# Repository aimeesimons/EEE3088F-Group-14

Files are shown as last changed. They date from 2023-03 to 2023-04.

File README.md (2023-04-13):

# EEE3088F-Group-14
Aimee Simons, Ashik John, Kudzi Kadzimu

1. 	Final Project has all the latest kicad files, 
	FullSchematic is the file with all modules combined

2.	PCB Submission contains PCB Files submitted for manufacture

3.	Report Submission contains weekly design assignment reports

4.	Miscellaneous files contains all other files used in the project, 
	THE FILES MAY NOT BE UP TO DATE WITH THE FINAL SUBMISSION!

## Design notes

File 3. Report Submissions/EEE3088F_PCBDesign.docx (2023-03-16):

Q1 Github [1]

https://github.com/aimeesimons/EEE3088F-Group-14.git

Q2 Power Subsystem Failure Management [2]

- Various failure management processes can be implemented that could cater for various failure instances. In the event of component failure, the datasheets of the different components must be carefully read to ensure that the components operate at rated electrical characteristics. The component packages are chosen to be sizes readily available elsewhere, such as the UCT white lab, in the event that components need to be replaced.
- If trace damage occurs, the various test points can be connected with means of an external soldered wire, thus forming an alternate route for current flow. The test points themselves can be used to check for continuity in the traces, and identify exact traces with damage.
- Where possible, components were selected to be basic parts, which the supplier is more likely to have ready access to. In the cases where extended parts need to be used, the different parts available can be sorted by stock available, thus mitigating the chances component shortage. In the event that component shortage still occurs, most components can be chosen to be common package sizes, so that they can be sourced and soldered on locally.
- Designs will be simulated beforehand, to lower chances of error. Test points will be added for debugging purposes and 0Ω resistors will be used to break connection and bypass the different components if required.

Q3 Sensing Subsystem Failure Management [2]

- Components could become damaged due to various circumstances, whether it be current overload or damage in transit. With regards to damage due to current overload, zero-ohm resistors can be placed within the circuit and used as fuses to prevent damages that could be caused to these components. Components damaged in transit could be remedied by removing that damaged component and soldering on an alternative component. If it is the worst-case scenario and most of the components fail, a breadboard can be used to show the functionality of the HAT, in the meantime, before making adjustments to the circuit schematic and/or ordering a new PCB.
- In terms of trace damage; this could be damage to the point of causing an open circuit; short wires could be soldered to connect components previously disconnected by damaged traces. Test points will be located at several points in the circuit to test continuity, which should indicate whether there has been any trace damage.
- In terms of availability of parts, on the JLCPCB website, The TTP223 chip seems to be out of stock and/or discontinued. A similar chip which works in the same way and is available was found as an alternative. In terms of specialised components, such as the use of a variable capacitor, which has very limited stock, this will prove to be trickier. An alternative would have to be to purchase a normal capacitor.
- There could also be errors in the design that went undetected and was only discovered upon manufacture. If the error has to do with the connections, traces could be purposefully damaged or open circuits can be made in order to physically make the correct connections using wires. As mentioned above, ordering a normal capacitor instead of a variable capacitor could prove to have some consequences. Ordering a specific capacitor would require calculations before purchase, in order to adjust the sensitivity of the touch sensor. This could, however, result in either a very sensitive touch sensor (too sensitive - meaning you can just hover your finger over the touch-pad and it will be detected) or not sensitive enough (meaning it will be very difficult for the chip to detect any touch at all). This capacitor connection should therefore not be too close to other components, as it would have to be easily removable and replaceable.

Q4 Microcontroller interfacing Failure Management [2]

To manage failures in our circuit design we can take.

(i) Component failure/destruction:

We will use high-quality but affordable components from a reputable manufacturer.

(ii) Trace damage:

Make sure the traces are not too thin and can handle the expected current.

Add protective components like TVS diodes to prevent damage to the traces.

Place vias to allow for the routing of the trace on the other side of the board.

(iii) Component shortage:

Choose components that are readily available.

Select alternative components with similar specifications that have huge stock and use them in the design.

Work with the PCB assembly house to find replacement components if the original component is no longer in stock.

(iv) Errors in circuit design:

Use simulation software to verify the circuit design before manufacturing.

Add test points for each circuit block to allow for easy debugging and testing.

Use a modular design approach to reduce the impact of design errors on the entire circuit.

By incorporating these measures, you can manage failures in your circuit design, ensuring a reliable and functional PCB.

Q5 Power Subsystem Schematic [2]

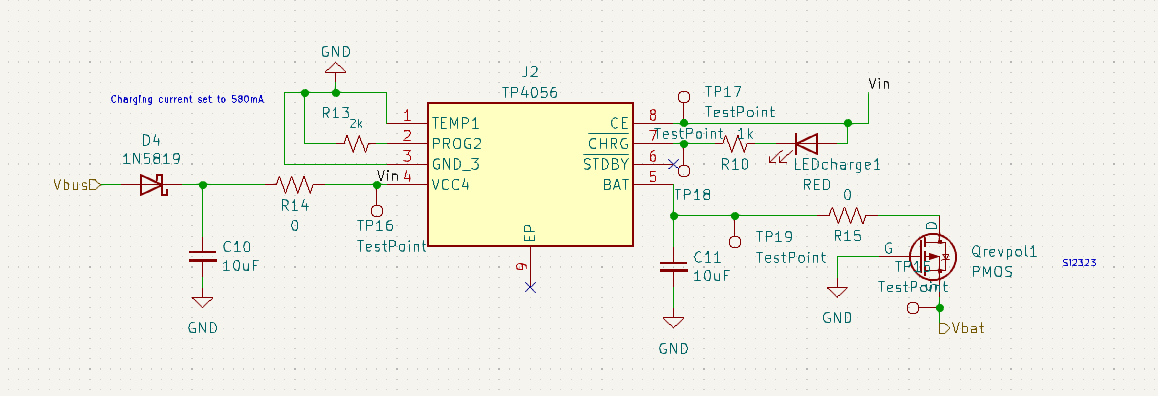
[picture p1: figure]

Charging Module

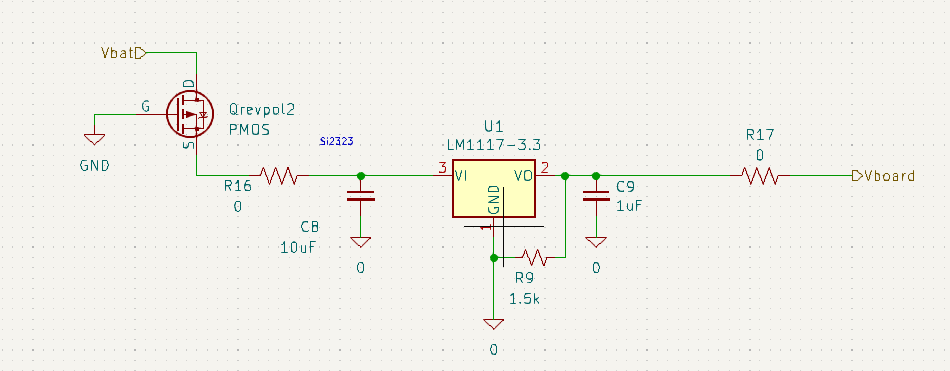
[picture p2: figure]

Regulating Module

Q6 Sensing Subsystem Schematics [2]

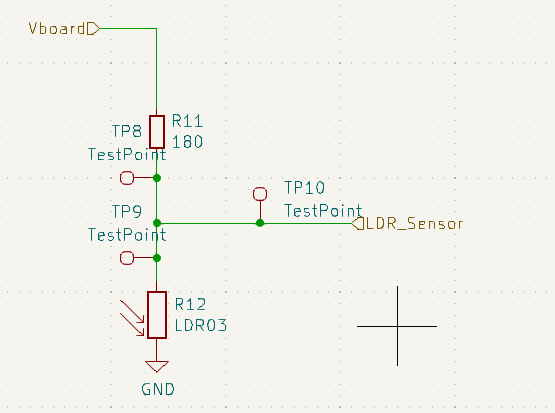
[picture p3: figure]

Analogue Sensor

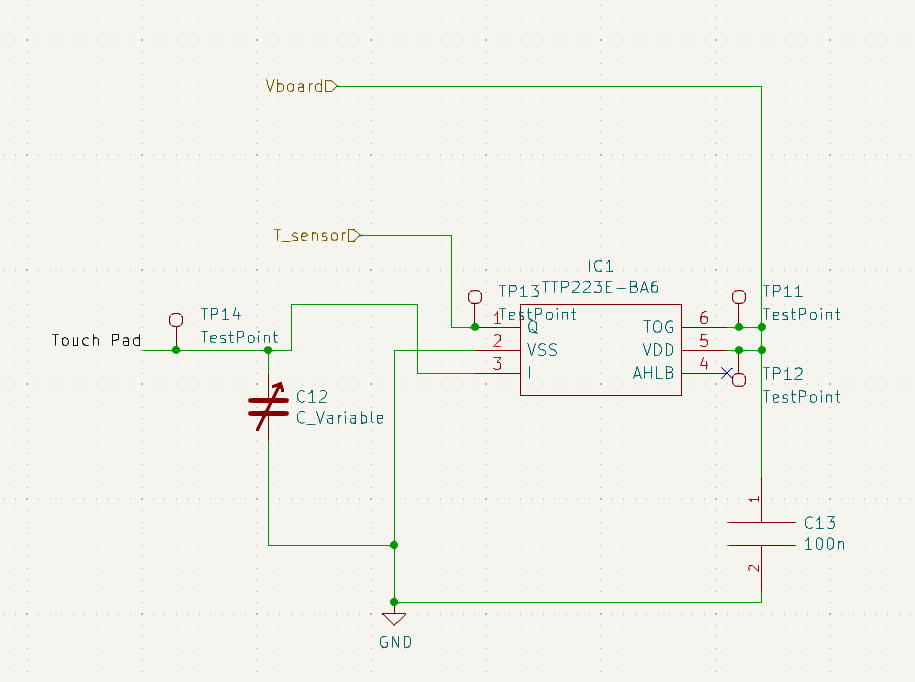
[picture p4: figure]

Digital Sensor

Q7 Microcontroller Interfacing Schematic [2]

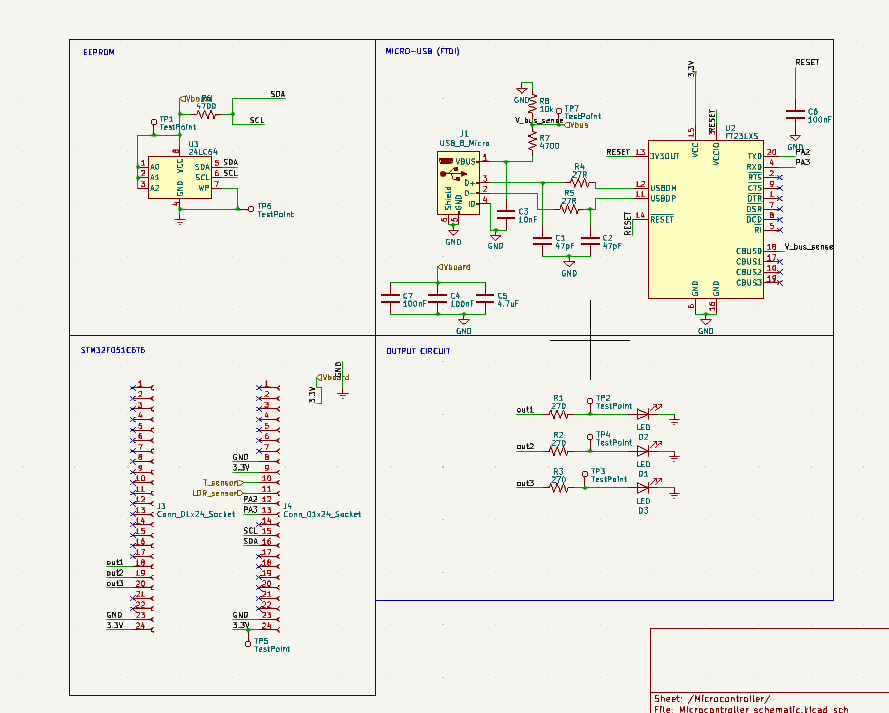
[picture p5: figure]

Microcontroller module

Q8 Updated ERCs [2]

- All hierarchal labels should be connected and should be connected properly.
- All net labels should be identical, example T_Sensor and T-sensor will cause confusion.
- All pins that are to be unconnected should have an indicator that they are unused.
- All components should be named uniquely, with no duplicates.
- Check that current is limited for important chips/components.

Q9 DRCs [2]

Q10 Updated BOM [5]

https://github.com/aimeesimons/EEE3088F-Group-14/blob/main/FullSchematic/FullSchematic/FullSchematic_Spreadsheet.xlsx

Q11 PCB [15]

EEE3088F PCB Design

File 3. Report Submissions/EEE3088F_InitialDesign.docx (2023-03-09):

Q1 Github [1]

https://github.com/aimeesimons/EEE3088F-Group-14.git

Q2 Power Subsystem Failure Management [5]

In text, briefly describe what measures you’ve taken in your circuit design that will enable you to manage failures such as but not necessarily limited to: (i) component failure/destruction, (ii) trace damage, (iii) component shortage (if at PCB assembly time your component is no longer in stock), (iv) errors in your circuit design that are only detected post manufacture.

Q3 Sensing Subsystem Failure Management [5]

(i) component failure/destruction

(ii) trace damage

(iii) component shortage (if at PCB assembly time your component is no longer in stock)

(iv) errors in your circuit design that are only detected post manufacture.

Q4 Microcontroller interfacing Failure Management [5]

In text, briefly describe what measures you’ve taken in your circuit design that will enable you to manage failures such as but not necessarily limited to: (i) component failure/destruction, (ii) trace damage, (iii) component shortage (if at PCB assembly time your component is no longer in stock), (iv) errors in your circuit design that are only detected post manufacture.

Q5 Power Subsystem Schematic [10]

Q6 Sensing Subsystem Schematics [10]

Q7 Microcontroller Interfacing Schematic [10]

Q8 Planned ERCs [5]

Q9 Updated BOM [4]

EEE3088F Initial Design

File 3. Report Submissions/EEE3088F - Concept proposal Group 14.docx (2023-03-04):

Q1 Enviro sensing HAT Concept [5]

Our team has come up with the idea to design and build a portable torch with auto-adjusting brightness. This project is engineered specifically for the age of load-shedding we are currently in, and caters to all audiences with a niche target on students. The device is easily rechargeable, using a 5V input, it could be connected to a laptop or a car. The board also uses an LED display system to represent the battery level, so users can use it safely without fear of suddenly running out of power. The design will be sleek and compact so that it fits like any other tool in a mechanics hand. The product has the potential to include a timer, which can have various uses.

Q2 Requirements [10]

- Scenario 1: Students

Students can make use of this torch during times of loadshedding, when more light is required during studying.

R1.1 The torch should be bright enough to light up a desk space

R1.2 Battery power should last at least two hours as per standard loadshedding schedules

R1.3 Should be able to recharge via regularly available USB cables.

- Scenario 2: Miners

Miners often go into deep shafts that can tend to get darker as you get further from a light source or the surface. It would be useful to have a torch in cases such as this.

R2.1 The product should be portable, and perhaps attach to a helmet

R2.2 Battery power should last long enough for working shifts

R2.3 In the case that the torch is attached to the helmet, the switch should be easy to find and use.

- Scenario 3: Mechanics

Mechanics need to shine light in tight workspaces.

R2.1 The product may need to be used as a headlight

R2.2 Product should be compact enough to shine light in tight spaces.

R2.3 Product should be robust considering its working environment

Q3 Project Subsystems Block Diagram [5]

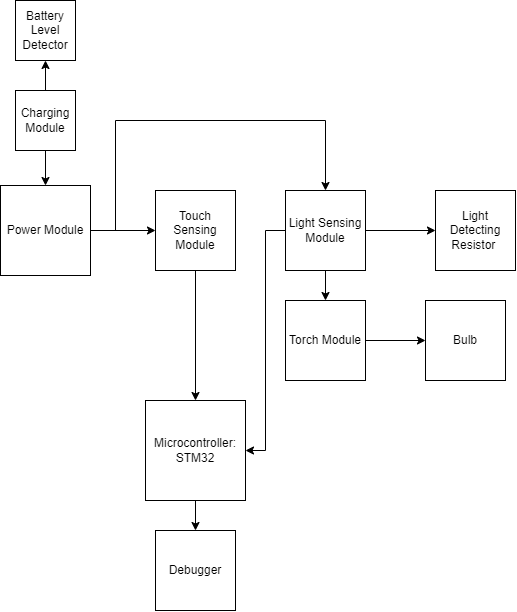
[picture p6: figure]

Group 14 Concept Proposal

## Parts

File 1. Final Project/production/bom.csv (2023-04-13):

Designator | Footprint | Quantity | Value | LCSC Part #
BT1 | 18650_Holder_SMD | 1 | Battery_Cell
C1, C13, C2, C3, C4 | 1206 | 5 | 100nF | C24497
C10, C11, C8, C9 | 1206 | 4 | 10uF | C13585
C5 | 0805 | 1 | 20pF | C1798
D1, D2, D3 | LED_D3.0mm_IRBlack | 3 | LED | C54142
D4, D6 | Schottky Diode | 2 | Schottky - 0.21@1A | C413465
D5 | 0805 | 1 | LED | C2296
IC1 | SOT-563 | 1 | TTP223E-BA6 | C1693666
J1 | MICROXNJ | 1 | USB_B_Micro | C404969
J2 | SOIC127P600X175-8N | 1 | TP4056 | C382139
J3 | PinHeader_1x04_P2.54mm_Vertical | 1 | Conn_01x04_Pin
J4, J5 | PinHeader_1x03_P2.54mm_Vertical | 2 | Conn_01x03_Pin
LEDcharge1 | 0603 | 1 | RED | C2286
P1 | Touch Pad | 1 | Touch Pad
Q1, Q2, Q3 | SOT-23 | 3 | SI2301CDS | C10487
Q4 | SOT-23 | 1 | 2N7002 | C8545
Qrevpol1, Qrevpol2 | Si2323 | 2 | PMOS | C10487
R1, R2, R3 | 0805 | 3 | 270R | C17590
R10 | 1206 | 1 | 1k | C4410
R11 | 0201 | 1 | 10k | C25804
R12 | R_LDR_5.0x4.1mm_P3mm_Vertical | 1 | LDR03 | C125627
R13 | 1206 | 1 | 2k | C17944
R14 | 0805 | 1 | 1M | C17514
R15, R16, R17, R4, R5, R7 | 1206 | 6 | 0 | C17888
R18 | 0805 | 1 | 10M | C26108
R19 | 0402 | 1 | 150k | C25755
R20 | 0805 | 1 | 2.05M | C784207
R21 | 0805 | 1 | 100k | 0805
R22, R8 | 0603 | 2 | 2M | C22976
R23 | 0201 | 1 | 150R | C22808
R24, R6 | RESC2013X65N | 2 | 4.7k | C23162
R9 | 1206 | 1 | 2.5M | C508414
TP1, TP10, TP11, TP12, TP13, TP14, TP15, TP16, TP19, TP2, TP20, TP21, TP22, TP23, TP3, TP4, TP5_2, TP5, TP6, TP7, TP8, TP9 | TestPoint_Pad_D2.0mm | 22 | TestPoint
TP17 | TestPoint_Keystone_5005-5009_Compact | 1 | TestPoint
TP18 | TestPoint_Pad_D2.5mm | 1 | TestPoint
U1 | SOT-23-3 | 1 | XC6206P332MR | C5446
U2 | SOIC-16_3.9x9.9mm_P1.27mm | 1 | CH340C | C84681
U3 | SOIC127P600X175-8N | 1 | AT24C256C | C6482
U6 | SOT-23 | 1 | CJ432 | C8499
U7 | SOIC-8_3.9x4.9mm_P1.27mm | 1 | NE5532 | C7426

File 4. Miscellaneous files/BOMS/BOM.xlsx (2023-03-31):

Component Count: | 79
Collated Components:
Item | Qty | Reference(s) | Value | Footprint | JLCPCB Part # | Populate | Price | Price ( 1 board) | Price (5 boards)
1 | 1 | BT1 | Battery_Cell | Library:18650_Holder_SMD | C2988620 | No | 1.41 | 1.41 | $7.05
2 | 4 | C1, C2, C3, C4 | 100nF | Capacitor_SMD:C_1206_3216Metric | C24497 | Yes | $0.0138 | 0.0414 | $0.07
3 | 1 | C5 | 20pF | Capacitor_THT:C_Disc_D4.7mm_W2.5mm_P5.00mm | C123152 | Yes | 0.08 | 0.08 | $0.40
4 | 4 | C8, C9, C10, C11 | 10uF | Capacitor_SMD:C_0603_1608Metric | C1691 | Yes | 0.08 | 0.24 | $1.20
5 | 1 | C13 | 100nF | Capacitor_THT:C_Disc_D4.3mm_W1.9mm_P5.00mm | C409812 | Yes | 0.08 | 0.32 | $1.60
6 | 3 | D1, D2, D3 | LED | LED_THT:LED_D3.0mm_IRBlack | C54142 | Yes | $0.0139 | 0.0417 | $0.07
7 | 1 | D4 | 1N5819 | Library:Temp Schottky | C437199 | Yes | 0.0167 | 0.0167 | $0.08
8 | 1 | D5 | LED | LED_SMD:LED_0201_0603Metric | C165982 | Yes | 0.0212 | 0.0212 | $0.11
9 | 1 | IC1 | TTP223E-BA6 | Package_TO_SOT_SMD:SOT-563 | C1693666 | Yes | 0.1 | 0.1 | $0.50
10 | 1 | J1 | USB_B_Micro | Library:MICROXNJ | C404969 | Yes | $0.0333 | $0.0333 | $0,1665
11 | 1 | J2 | TP4056 | Library:SOIC127P600X175-8N | C382139 | Yes | 0.11 | 0.11 | $0.55
12 | 2 | J3, J4 | Conn_01x03_Pin | Connector_PinHeader_2.54mm:PinHeader_1x03_P2.54mm_Vertical | N/A | No | N/A | N/A | N/A
13 | 1 | LEDcharge1 | RED | LED_THT:LED_D3.0mm_IRBlack | C2286 | Yes | 0.01 | 0.01 | $0.05
14 | 1 | P1 | Touch Pad | Library:Touch Pad | N/A |  | 0 | 0 | $0.00
15 | 2 | Q1, Q3 | IRLML6402 | Package_TO_SOT_SMD:SOT-23 | C518785 | Yes | 0.5 | 0.5 | $0.25
16 | 1 | Q2 | IRLML6402 | Package_TO_SOT_SMD:SOT-23 | C518785 | Yes | 0.05 | 0.5 | $0.25
17 | 1 | Q4 | 2N7002 | Package_TO_SOT_SMD:SOT-23 | C111971 | Yes | 0.06 | 0.06 | $0.30
18 | 2 | Qrevpol1, Qrevpol2 | PMOS | Library:Si2323 | C5337196 | Yes | 0.09 | 0.18 | $0.90
19 | 3 | R1, R2, R3 | 270R | Resistor_SMD:R_1206_3216Metric | C4466 | Yes | $0.0039 | 0.0117 | $0.58
20 | 6 | R4, R5, R7, R15, R16, R17 | 0 | Resistor_SMD:R_1206_3216Metric | C17888 | Yes | 0.003 | 0.012 | $0.06
21 | 1 | R 6 | 4700 | Library:RESC2013X65N | C23162 | Yes | 0.001 | 0.001 | $0.01
22 | 2 | R8, R22 | 2M | Resistor_SMD:R_0603_1608Metric | C465466 | Yes | 0.01 | 0.01 | $0.05
23 | 1 | R 9 | 2.5M | Resistor_SMD:R_1206_3216Metric | C508414 | Yes | 0.03 | 0.03 | $0.15
24 | 1 | R 10 | 1k | Resistor_SMD:R_1206_3216Metric | C4410 | Yes | 0.001 | 0.001 | $0.01
25 | 1 | R 11 | 180 | Resistor_SMD:R_0201_0603Metric | C22828 | Yes | 0.0017 | 0.0017 | $0.01
26 | 1 | R 12 | LDR03 | OptoDevice:R_LDR_5.0x4.1mm_P3mm_Vertical | C125627 | Yes | 0.04 | 0.04 | $0.20
27 | 1 | R 13 | 2k | Resistor_SMD:R_1206_3216Metric | C17944 | Yes | 0.01 | 0.01 | $0.05
28 | 1 | R 14 | 1M | Resistor_SMD:R_0805_2012Metric | C416080 | Yes | 0.01 | 0.01 | $0.05
29 | 1 | R 18 | 10M | Resistor_SMD:R_0805_2012Metric | C26108 | Yes | 0.01 | 0.01 | $0.05
30 | 1 | R 19 | 150k | Resistor_SMD:R_0402_1005Metric | C429049 | Yes | 0.01 | 0.01 | $0.05
31 | 1 | R 20 | 2.05M | Resistor_SMD:R_0805_2012Metric | C784207 | Yes | 0.01 | 0.01 | $0.05
32 | 1 | R 21 | 100k | Resistor_SMD:R_0805_2012Metric | C465471 | Yes | 0.01 | 0.01 | $0.05
33 | 1 | R 23 | 150R | Resistor_SMD:R_0201_0603Metric | C136932 | Yes | 0.01 | 0.01 | $0.05
34 | 19 | TP1, TP2, TP3, TP4, TP5, TP6, TP7, TP8, TP9, TP10, TP11, TP12, TP13, TP14, TP15, TP16, TP19, TP20, TP21 | TestPoint | TestPoint:TestPoint_Pad_D2.0mm | N/A |  | $0 | 0 | $0.00
35 | 1 | TP17 | TestPoint | TestPoint:TestPoint_Keystone_5005-5009_Compact | N/A |  | 0 | 0 | $0.00
36 | 1 | TP18 | TestPoint | TestPoint:TestPoint_Pad_D2.5mm
37 | 1 | U1 | LM1117-3.3 | Library:SOT230P700X180-4N | C126027 | Yes | 0.072 | 0.072 | $0.36
38 | 1 | U2 | CH340C | Package_SO:SOIC-16_3.9x9.9mm_P1.27mm | C84681 | Yes | 0.47 | 0.47 | $2.35
39 | 1 | U3 | 24LC64 | Library:SOIC127P600X175-8N | C511260 | Yes | $0.7664 | $0.7664 | $3.83
40 | 1 | U4 | STM32F051C6T6 | Library:STM32F051C6T6 | C5456 | No | 0 | 0 | $0.00
41 | 1 | U5 | OP184 | Library:SOIC127P600X175-8N | C690879 | Yes | 3.17 | 3.17 | $15.85
42 | 1 | U6 | CJ432 | Package_TO_SOT_SMD:SOT-23 | C8499 | Yes | 0.06 | 0.06 | $0.30
 |  |  |  |  |  |  |  |  | $37.48

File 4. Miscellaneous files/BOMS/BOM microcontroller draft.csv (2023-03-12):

Source: | C:\Users\kkadz\Documents\1 HAT project\1 HAT project.sch
Date: | 2023/03/06 08:31:40
Tool: | Eeschema (5.1.10)-1
Generator: | C:\Program Files\KiCad\bin\scripting\plugins/bom_csv_grouped_by_value.py
Component Count: | 7
Individual Components:
Item | Qty | Reference(s) | Value | LibPart | Footprint | Datasheet | Price
 |  | D1 | LED | Device:LED | LED_SMD:LED-APA102-2020 | ~ | 1,04
 |  | D2 | LED | Device:LED | LED_SMD:LED-APA102-2020 | ~ | 1,04
 |  | D3 | LED | Device:LED | LED_SMD:LED-APA102-2020 | ~ | 1,04
 |  | R1 | 200 | Device:R | Resistor_SMD:R_0201_0603Metric | ~ | 0,040
 |  | R2 | 200 | Device:R | Resistor_SMD:R_0201_0603Metric | ~ | 0,040
 |  | R3 | 200 | Device:R | Resistor_SMD:R_0201_0603Metric | ~ | 0,040
 |  | U1 | STM32F051C6Tx | MCU_ST_STM32F0:STM32F051C6Tx | Package_QFP:LQFP-48_7x7mm_P0.5mm | http://www.st.com/st-web-ui/static/active/en/resource/technical/document/datasheet/DM00039193.pdf
Collated Components:
Item | Qty | Reference(s) | Value | LibPart | Footprint | Datasheet | Price
1 | 3 | D1, D2, D3 | LED | Device:LED | LED_SMD:LED-APA102-2020 | ~ | 1,04
2 | 1 | R1 | 200 | Device:R | Resistor_SMD:R_0201_0603Metric | ~ | 0,040
3 | 2 | R2, R3 | 200 | Device:R | Resistor_SMD:R_0201_0603Metric | ~ | 0,040
4 | 1 | U1 | STM32F051C6Tx | MCU_ST_STM32F0:STM32F051C6Tx | Package_QFP:LQFP-48_7x7mm_P0.5mm | http://www.st.com/st-web-ui/static/active/en/resource/technical/document/datasheet/DM00039193.pdf

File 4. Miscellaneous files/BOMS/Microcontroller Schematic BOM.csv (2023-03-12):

Source: | C:\Users\kkadz\Documents\Microcontroller interfacing\Microcontroller Schematic.kicad_sch
Date: | 2023/03/12 18:25:58
Tool: | Eeschema (7.0.0)
Generator: | C:\Program Files\KiCad\7.0\bin\scripting\plugins/bom_csv_grouped_by_value.py
Component Count: | 30
Collated Components:
Item | Qty | Reference(s) | Value | LibPart | Footprint | Datasheet | DNP | Price
1 | 2 | C1, C2 | 47pF | Device:C |  | ~ |  |  | $0.0447
2 | 1 | C3 | 10nF | Device:C |  | ~ |  |  | $0.0242
3 | 3 | C4, C6, C7 | 100nF | Device:C |  | ~ |  |  | $0.0685
4 | 1 | C5 | 4.7uF | Device:C |  | ~ |  |  | $0.0872
5 | 3 | D1, D2, D3 | LED | Device:LED | LED_SMD:LED-APA102-2020 | ~ |  |  | $0.0139
6 | 1 | J1 | USB_B_Micro | Connector:USB_B_Micro |  | ~ |  |  | $0.0273
7 | 2 | J2, J3 | Conn_01x24_Socket | Connector:Conn_01x24_Socket |  | ~ |  |  | $0
8 | 3 | R1, R2, R3 | 270 | Device:R_US |  | ~ |  |  | $0.0039
9 | 2 | R4, R5 | 27R | Device:R_US |  | ~ |  |  | $0.0070
10 | 2 | R6, R7 | 4700 | Device:R_US |  | ~ |  |  | $0.0005
11 | 1 | R8 | 10k | Device:R_US |  | ~ |  |  | $0.0010
12 | 7 | TP1, TP2, TP3, TP4, TP5, TP6, TP7 | TestPoint | Connector:TestPoint |  | ~ |  |  | $0.0438
13 | 1 | U2 | FT231XS | Interface_USB:FT231XS | Package_SO:SSOP-20_3.9x8.7mm_P0.635mm | https://www.ftdichip.com/Support/Documents/DataSheets/ICs/DS_FT231X.pdf |  |  | $3.1015
14 | 1 | U3 | 24LC64 | Memory_EEPROM:24LC64 |  | http://ww1.microchip.com/downloads/en/DeviceDoc/21189f.pdf |  |  | $0.5172

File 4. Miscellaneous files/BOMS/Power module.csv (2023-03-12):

Source: | C:\Users\ASHIK\OneDrive - University of Cape Town\Course\2023\EEE3088F\Power Submodule design\Power module\Power module.sch
Date: | 2023/03/06 09:27
Tool: | Eeschema (5.1.10)-1
Generator: | C:\Program Files\KiCad\bin\scripting\plugins/bom_csv_grouped_by_value.py
Component Count: | 12
Individual Components:
Item | Qty | Reference(s) | Value | LibPart | Footprint | Datasheet | Price (USD) | Price (ZAR)
1 | 1 | BT1 | Battery_Cell | Device:Battery_Cell |  | ~
2 | 1 | C1 | 4.7u | Device:C_Small | CL10A475KO8NNNC | ~ | 0,01 | 0,1819
3 | 1 | C2 | 4.7u | Device:C_Small | CL10A475KO8NNNC | ~ | 0,01 | 0,1819
4 | 1 | C3 | 10uF | Device:C_Small | CL31A106KBHNNNE | ~ | 0,03 | 0,5457
5 | 1 | C4 | 1uF | Device:C_Small | CL05A105KP5NNNC | ~ | 0,01 | 0,1819
6 | 1 | CG1 | MCP73831T-2ACI/OT | MCP73831-2-OT | Package_TO_SOT_SMD:SOT-23-5 | http://ww1.microchip.com/downloads/en/DeviceDoc/20001984g.pdf | 0,7664 | 13,940816
7 | 1 | D1 | 1N5819 | Diode:1N5819 | Diode_THT:D_DO-41_SOD81_P10.16mm_Horizontal | http://www.vishay.com/docs/88525/1n5817.pdf | 0,0167 | 0,303773
8 | 1 | Q2 | SI2305DS-T1-GE3 | Transistor_FET:Si2371EDS | Package_TO_SOT_SMD:SOT-23 | http://www.vishay.com/docs/63924/si2371eds.pdf | 0,072 | 1,30968
9 | 1 | R1 | 2k | Device:R_Small_US |  | ~ | 0,001 | 0,01819
10 | 1 | R2 | 47k | Device:R_Small_US |  | ~ | 0,001 | 0,01819
11 | 1 | R3 | 1.5k | Device:R_Small_US |  | ~ | 0,001 | 0,01819
12 | 1 | U2 | LM1117-3.3 | Regulator_Linear:LM1117-3.3 |  | http://www.ti.com/lit/ds/symlink/lm1117.pdf | 0,146 | 2,65574
 |  |  |  | Total: |  |  | 1,064 | 19,35416
Collated Components:
Item | Qty | Reference(s) | Value | LibPart | Footprint | Datasheet | Price
1 | 1 | BT1 | Battery_Cell | Device:Battery_Cell |  | ~
2 | 2 | C1, C2 | 4.7u | Device:C_Small | CL10A475KO8NNNC | ~ | 0.01
3 | 1 | C3 | 10uF | Device:C_Small | CL31A106KBHNNNE | ~ | 0.03
4 | 1 | C4 | 1uF | Device:C_Small | CL05A105KP5NNNC | ~ | 0.01
5 | 1 | CG1 | MCP73831T-2ACI/OT | MCP73831-2-OT | Package_TO_SOT_SMD:SOT-23-5 | http://ww1.microchip.com/downloads/en/DeviceDoc/20001984g.pdf | 0.7664
6 | 1 | D1 | 1N5819 | Diode:1N5819 | Diode_THT:D_DO-41_SOD81_P10.16mm_Horizontal | http://www.vishay.com/docs/88525/1n5817.pdf | 0.0167
7 | 1 | Q2 | SI2305DS-T1-GE3 | Transistor_FET:Si2371EDS | Package_TO_SOT_SMD:SOT-23 | http://www.vishay.com/docs/63924/si2371eds.pdf | 0.072
8 | 1 | R1 | 2k | Device:R_Small_US |  | ~ | 0.001
9 | 1 | R2 | 47k | Device:R_Small_US |  | ~ | 0.001
10 | 1 | R3 | 1.5k | Device:R_Small_US |  | ~ | 0.001
11 | 1 | U2 | LM1117-3.3 | Regulator_Linear:LM1117-3.3 |  | http://www.ti.com/lit/ds/symlink/lm1117.pdf | 0.146

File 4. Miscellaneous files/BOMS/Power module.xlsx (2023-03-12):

Source: | C:\Users\ASHIK\OneDrive - University of Cape Town\Course\2023\EEE3088F\Power Submodule design\Power module\Power module.sch
Date: | 2023-03-06 09:27
Tool: | Eeschema (5.1.10)-1
Generator: | C:\Program Files\KiCad\bin\scripting\plugins/bom_csv_grouped_by_value.py
Component Count: | 12
Individual Components:
Item | Qty | Reference(s) | Value | LibPart | Price
1 | 1 | BT1 | Battery_Cell | Device:Battery_Cell
2 | 1 | C1 | 4.7u | Device:C_Small | 0.01
3 | 1 | C2 | 4.7u | Device:C_Small | 0.01
4 | 1 | C3 | 10uF | Device:C_Small | 0.03
5 | 1 | C4 | 1uF | Device:C_Small | 0.01
6 | 1 | CG1 | MCP73831T-2ACI/OT | MCP73831-2-OT | 0.7664
7 | 1 | D1 | 1N5819 | Diode:1N5819 | 0.0167
8 | 1 | Q2 | SI2305DS-T1-GE3 | Transistor_FET:Si2371EDS | 0.072
9 | 1 | R 1 | 2k | Device:R_Small_US | 0.001
10 | 1 | R 2 | 47k | Device:R_Small_US | 0.001
11 | 1 | R 3 | 1.5k | Device:R_Small_US | 0.001
12 | 1 | U2 | LM1117-3.3 | Regulator_Linear:LM1117-3.3 | 0.146
 |  |  |  | Total: | 1.064
Collated Components:
Item | Qty | Reference(s) | Value | LibPart | Price
1 | 1 | BT1 | Battery_Cell | Device:Battery_Cell
2 | 2 | C1, C2 | 4.7u | Device:C_Small | 0.01
3 | 1 | C3 | 10uF | Device:C_Small | 0.03
4 | 1 | C4 | 1uF | Device:C_Small | 0.01
5 | 1 | CG1 | MCP73831T-2ACI/OT | MCP73831-2-OT | 0.7664
6 | 1 | D1 | 1N5819 | Diode:1N5819 | 0.0167
7 | 1 | Q2 | SI2305DS-T1-GE3 | Transistor_FET:Si2371EDS | 0.072
8 | 1 | R 1 | 2k | Device:R_Small_US | 0.001
9 | 1 | R 2 | 47k | Device:R_Small_US | 0.001
10 | 1 | R 3 | 1.5k | Device:R_Small_US | 0.001
11 | 1 | U2 | LM1117-3.3 | Regulator_Linear:LM1117-3.3 | 0.146

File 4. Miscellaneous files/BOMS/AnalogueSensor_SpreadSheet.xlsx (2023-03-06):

Source: | C:\Users\Aimee Simons\Desktop\2023\EEE3088F-Group-14\AnalogueSensor\AnalogueSensor.sch
Date: | 2023-03-05 20:59
Tool: | Eeschema (5.1.10)-1
Generator: | C:\Program Files\KiCad\bin\scripting\plugins/bom_csv_grouped_by_value.py
Component Count: | 2
Individual Components:
Item | Qty | Reference(s) | Value | LibPart | Footprint | Datasheet | Price (Dollars)
 |  | R 1 | 180 | Device:R_Small | Resistor_SMD:R_0201_0603Metric | ~ | 0.0017
 |  | R 2 | LDR03 | Sensor_Optical:LDR03 | OptoDevice:R_LDR_10x8.5mm_P7.6mm_Vertical | http://www.elektronica-componenten.nl/WebRoot/StoreNL/Shops/61422969/54F1/BA0C/C664/31B9/2173/C0A8/2AB9/2AEF/LDR03IMP.pdf | 0.04
Collated Components:
Item | Qty | Reference(s) | Value | LibPart | Footprint | Datasheet | Price (Dollars) | Price (Rands)
1 | 1 | R 1 | 180 | Device:R_Small | Resistor_SMD:R_0201_0603Metric | ~ | 0.0017 | 0.030838
2 | 1 | R 2 | LDR03 | Sensor_Optical:LDR03 | OptoDevice:R_LDR_10x8.5mm_P7.6mm_Vertical | http://www.elektronica-componenten.nl/WebRoot/StoreNL/Shops/61422969/54F1/BA0C/C664/31B9/2173/C0A8/2AB9/2AEF/LDR03IMP.pdf | 0.04 | 0.7256
 |  |  |  |  |  |  | 0.0417 | 0.756438

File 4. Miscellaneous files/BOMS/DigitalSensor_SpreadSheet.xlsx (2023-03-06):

Source: | C:\Users\Aimee Simons\Desktop\2023\EEE3088F-Group-14\DigitalSensor\DigitalSensor.sch
Date: | 2023-03-05 20:47
Tool: | Eeschema (5.1.10)-1
Generator: | C:\Program Files\KiCad\bin\scripting\plugins/bom_csv_grouped_by_value.py
Component Count: | 3
Individual Components:
Item | Qty | Reference(s) | Value | LibPart | Footprint | Datasheet | Description | Height | Manufacturer_Name | Manufacturer_Part_Number | Price (Dollars)
 |  | C1 | 100n | pspice:CAP | Capacitor_THT:CP_Axial_L10.0mm_D4.5mm_P15.00mm_Horizontal | ~ |  |  |  |  | 0.0009
 |  | C2 | C_Variable | Device:C_Variable | Capacitor_SMD:C_Trimmer_Murata_TZC3 | ~ |  |  |  |  | 0.3067
 |  | IC1 | TTP223E-BA6 | TTP223E-BA6:TTP223E-BA6 | TTP223E-BA6:SOT95P285X126-6N | https://datasheet.lcsc.com/szlcsc/1810251711_Tontek-Design-Tech-TTP223E-BA6_C129457.pdf | SOT-23-6 Touch Screen Controller ICs | 1.26 | Tontec | TTP223E-BA6 | 0.1568
Collated Components:
Item | Qty | Reference(s) | Value | LibPart | Footprint | Datasheet | Description | Height | Manufacturer_Name | Manufacturer_Part_Number | Price(Dollars) | Price (Rands)
1 | 1 | C1 | 100n | pspice:CAP | Capacitor_THT:CP_Axial_L10.0mm_D4.5mm_P15.00mm_Horizontal | ~ |  |  |  |  | 0.0009 | 0.016326
2 | 1 | C2 | C_Variable | Device:C_Variable | Capacitor_SMD:C_Trimmer_Murata_TZC3 | ~ |  |  |  |  | 0.3067 | 5.563538
3 | 1 | IC1 | TTP223E-BA6 | TTP223E-BA6:TTP223E-BA6 | TTP223E-BA6:SOT95P285X126-6N | https://datasheet.lcsc.com/szlcsc/1810251711_Tontek-Design-Tech-TTP223E-BA6_C129457.pdf | SOT-23-6 Touch Screen Controller ICs | 1.26 | Tontec | TTP223E-BA6 | 0.1568 | 2.844352
 |  |  |  |  |  |  |  |  |  |  | 0.4644 | 8.424216

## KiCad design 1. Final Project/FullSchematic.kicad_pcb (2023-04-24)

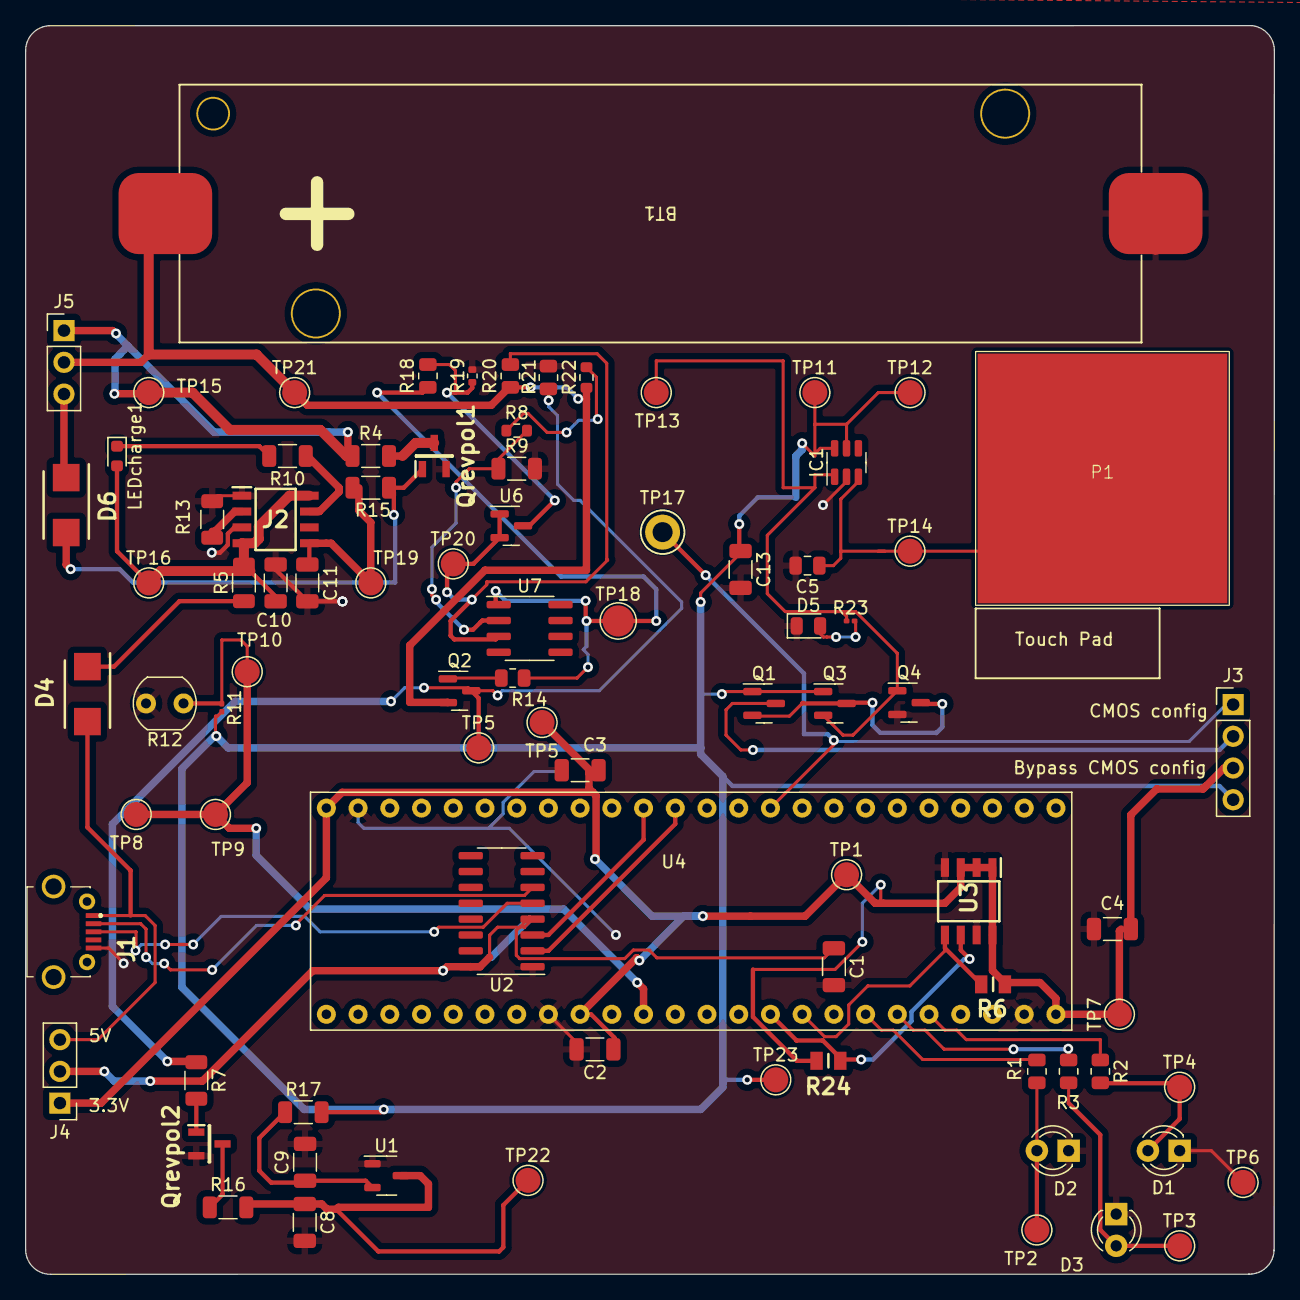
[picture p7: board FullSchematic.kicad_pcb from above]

Board: 2 copper layers, 100.0 x 100.0 mm, 85 parts (0 on the bottom side), 46 nets.

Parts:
BT1: Battery_Cell; 18650_Holder_SMD
C1, C2, C3, C4, C13: 100nF; C_1206_3216Metric
C5: 20pF; C_0805_2012Metric
C8, C9, C10, C11: 10uF; C_1206_3216Metric
D1, D2, D3: LED; LED_D3.0mm_IRBlack
D4, D6: Schottky - 0.21@1A; Schottky Diode
D5: LED; LED_0805_2012Metric
IC1: TTP223E-BA6; SOT-23-6
J1: USB_B_Micro; MICROXNJ
J2: TP4056; SOIC127P600X175-8N
J3: Conn_01x04_Pin; PinHeader_1x04_P2.54mm_Vertical
J4, J5: Conn_01x03_Pin; PinHeader_1x03_P2.54mm_Vertical
LEDcharge1: RED; LED_0603_1608Metric
P1: Touch Pad
Q1, Q2, Q3: SI2301CDS; SOT-23
Q4: 2N7002; SOT-23
Qrevpol1, Qrevpol2: PMOS; Si2323
R1, R2, R3: 270R; R_0805_2012Metric
R4, R5, R7, R15, R16, R17: 0; R_1206_3216Metric
R6, R24: 4.7k; RESC2013X65N
R8, R22: 2M; R_0603_1608Metric
R9: 2.5M; R_1206_3216Metric
R10: 1k; R_1206_3216Metric
R11: 10k; R_0201_0603Metric
R12: LDR03; R_LDR_5.0x4.1mm_P3mm_Vertical
R13: 2k; R_1206_3216Metric
R14: 1M; R_0805_2012Metric
R18: 10M; R_0805_2012Metric
R19: 150k; R_0402_1005Metric
R20: 2.05M; R_0805_2012Metric
R21: 100k; R_0805_2012Metric
R23: 150R; R_0201_0603Metric
TP1, TP2, TP3, TP4, TP5, TP5#2, TP6, TP7, TP8, TP9, TP10, TP11, TP12, TP13, TP14, TP15, TP16, TP19, TP20, TP21, TP22, TP23: TestPoint; TestPoint_Pad_D2.0mm
TP17: TestPoint; TestPoint_Keystone_5005-5009_Compact
TP18: TestPoint; TestPoint_Pad_D2.5mm
U1: XC6206P332MR; SOT-23-3
U2: CH340C; SOIC-16_3.9x9.9mm_P1.27mm
U3: AT24C256C; SOIC127P600X175-8N
U4: STM32F051C6T6
U6: CJ432; SOT-23
U7: NE5532; SOIC-8_3.9x4.9mm_P1.27mm

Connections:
/Microcontroller/3.3V: C2.1, C3.1, C4.1, J3.3, J4.1, R6.1, R24.1, TP1.1, TP5#2.1, TP7.1, U3.1 (A0), U3.2 (A1), U3.3 (A2), U3.8 (VCC), U4.9 (V+), U4.24 (V+), U4.48 (V+)
/Microcontroller/5V: D4.2 (A), J1.1 (VBUS), J4.3
/Microcontroller/LDR_sensor: R11.2, R12.1, TP8.1, TP9.1, TP10.1, U4.11 (PA1)
/Microcontroller/Rx: U2.2 (TXD), U4.37 (PA14)
/Microcontroller/SCL: R24.2, U3.6 (SCL), U4.15 (PA5)
/Microcontroller/SDA: R6.2, U3.5 (SDA), U4.16 (PA6)
/Microcontroller/T_sensor: J3.1, TP17.1, U4.34 (PA13)
/Microcontroller/Tx: U2.3 (RXD), U4.38 (PA15)
/Microcontroller/out1: R1.1, U4.18 (PB0)
/Microcontroller/out2: R2.1, U4.20 (PB2)
/Microcontroller/out3: R3.1, U4.19 (PB1)
/Output of Touch Sensor: IC1.1 (Q), Q3.2 (G), Q4.1 (G), R23.1, TP13.1
/Pin 2: J3.2, Q1.3 (S)
/Power Module/Charging/Vbat: BT1.1 (+), J5.2, Q2.2 (S), R20.1, R22.1, TP21.1
/Power Module/Charging/Vin: C10.1, J2.4 (VCC4), J2.8 (CE), LEDcharge1.2 (A), R5.2, TP16.1
/Power Module/Regulating/Vbat: Q2.3 (D), R7.1, R21.1, TP5.1
/Power Module/Regulating/Vin: C8.1, R16.2, TP22.1, U1.3 (VI)
/Vboard: C13.1, IC1.5 (VDD), IC1.6 (TOG), J3.4, Q1.1 (D), Q3.1 (D), R11.1, R17.2, TP11.1, TP12.1, TP23.1
GND: BT1.2 (-), C1.2, C2.2, C3.2, C4.2, C5.2, C8.2, C9.2, C10.2, C11.2, C13.2, D1.1 (K), D2.1 (K), D3.1 (K), D5.1 (K), IC1.2 (VSS), J1.5 (GND), J2.1 (TEMP1), J2.3 (GND_3), Q4.2 (S), Qrevpol1.2 (G), Qrevpol2.2 (G), R9.2, R12.2, R13.1, R19.2, R21.2, TP6.1, U1.1 (GND), U2.1 (GND), U3.4 (GND), U3.7 (WP), U4.8 (GND), U4.23 (GND), U4.47 (GND)
unnamed: C1.1, J4.2, U2.4 (V3), U2.16 (VCC)
unnamed: D1.2 (A), R2.2, TP4.1
unnamed: D2.2 (A), R1.2, TP2.1
unnamed: D3.2 (A), R3.2, TP3.1
unnamed: D4.1 (K), R5.1
unnamed: D5.2 (A), R23.2
unnamed: D6.2 (A), Qrevpol1.1 (D), R15.2
unnamed: D6.1 (K), J5.3
unnamed: C5.1, IC1.3 (I), P1.Touch Pad1, TP14.1
unnamed: J1.3 (D+), U2.5 (UD+)
unnamed: J1.2 (D-), U2.6 (UD-)
unnamed: C11.1, J2.5 (BAT), R15.1, TP19.1
unnamed: J2.2 (PROG2), R13.2
unnamed: J2.7 (~CHRG), R10.1
unnamed: J5.1, R4.1, TP15.1
unnamed: LEDcharge1.1 (K), R10.2
unnamed: Q1.2 (G), Q3.3 (S), Q4.3 (D)
unnamed: Q2.1 (G), R14.1
unnamed: Qrevpol1.3 (S), R4.2
unnamed: Qrevpol2.1 (D), R7.2
unnamed: Qrevpol2.3 (S), R16.1
unnamed: R14.2, R18.1, TP18.1, U7.1
unnamed: R8.1, R22.2
unnamed: C9.1, R17.1, U1.2 (VO)
unnamed: R18.2, R19.1, U6.3 (A)
unnamed: R20.2, TP20.1, U6.1 (REF), U6.2 (K), U7.3 (+)
unnamed: R8.2, R9.1, U7.2 (-)

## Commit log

2023-03-04 Added Sensor Files
    [AnalogueSensor.kicad_pcb, AnalogueSensor.sch, DigitalSensor.kicad_pcb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]
2023-03-04 Drew up draft schematic for analogue sensor
    [AnalogueSensor.sch]
2023-03-04 Created Bill Spreadsheet
    [BillOfMaterialsSensing.xlsx]
2023-03-04 Creating Digital Sensor Schematic
    [DigitalSensor.sch, TTP223-BA6_2023-03-04.schdoc]
2023-03-05 added component values
    [AnalogueSensor.csv, AnalogueSensor.sch, DigitalSensor.sch]
2023-03-05 finalising draft schematics
    [AnalogueSensor.csv, AnalogueSensor.sch, DigitalSensor.csv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]
2023-03-05 Not needeed
    [BillOfMaterialsSensing.xlsx]
2023-03-06 Convert to excel spreadsheet
    [AnalogueSensor_SpreadSheet.xlsx, DigitalSensor_SpreadSheet.xlsx]
2023-03-06 Add files via upload
    Convert to spreadsheet
    [AnalogueSensor_SpreadSheet.xlsx]
2023-03-06 Add files via upload
    Convert to excel spreadsheet
    [DigitalSensor_SpreadSheet.xlsx]
2023-03-09 Updated schematics
    [DigitalSensor.sch]
2023-03-11 Combining Schemtics
    [AnalogueSensor.csv, AnalogueSensor.kicad_pcb, AnalogueSensor.sch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]
2023-03-11 global changes
    [Microcontroller Schematic.kicad_sch]
2023-03-12 Combing all schematics
    [AnalogueSensor.csv, AnalogueSensor.kicad_pcb, AnalogueSensor.kicad_sch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]
2023-03-12 Moved to full schematic folder
    [AnalogueSensor.kicad_sch, AnalogueSensor.sch, DigitalSensor.kicad_sch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]
2023-03-13 completed and generated BOM
    [Charging Module.kicad_sch, DigitalSensor.kicad_sch, FullSchematic.csv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]
2023-03-14 added power flags
    [Microcontroller Schematic.kicad_sch, Regulating Module.kicad_sch]
2023-03-15 updated footprints
    [AnalogueSensor.kicad_sch, DigitalSensor.kicad_sch]
2023-03-16 added more footprints
    [AnalogueSensor.kicad_sch, Charging Module.kicad_sch, DigitalSensor.kicad_sch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]
2023-03-16 Before merge-aimee
    [Charging Module.kicad_sch, Microcontroller Schematic.kicad_sch, Regulating Module.kicad_sch]
2023-03-16 Merging g to be committed:
    [Microcontroller Schematic.kicad_sch]
2023-03-16 Corrected errors
    [Microcontroller Schematic.kicad_sch]
2023-03-16 tried to go to previous version
    [Charging Module.kicad_sch, Microcontroller Schematic.kicad_sch, Regulating Module.kicad_sch]
2023-03-16 almost there
    [Microcontroller Schematic.kicad_sch]
2023-03-16 Opening MicroController
    [AnalogueSensor.kicad_sch, Charging Module.kicad_sch, DigitalSensor.kicad_sch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]
2023-03-16 adding of all footprints
    [Charging Module.kicad_sch, DigitalSensor.kicad_sch, Microcontroller Schematic.kicad_sch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]
2023-03-17 updated schematics and footprints
    [FullSchematic.kicad_sch, Microcontroller Schematic.kicad_sch, Power module.kicad_sch]
2023-03-18 updated schematic and footprints
    [AnalogueSensor.kicad_sch, Charging Module.kicad_sch, DigitalSensor.kicad_sch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]
2023-03-18 connected sensors adnd created touch pad
    [AnalogueSensor.kicad_sch, Charging Module.kicad_sch, DigitalSensor.kicad_sch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]
2023-03-19 connected microcontroller
    [FullSchematic.kicad_pcb]
2023-03-20 finalised pcb design
    [AnalogueSensor.csv, AnalogueSensor.kicad_pcb, AnalogueSensor.kicad_sch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]
2023-03-20 copied correct file
    [AnalogueSensor.csv, AnalogueSensor.kicad_pcb, AnalogueSensor.kicad_sch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]
2023-03-21 generated Gerber files
    [FullSchematic-B_Cu.gbr, FullSchematic-B_Mask.gbr, FullSchematic-B_Paste.gbr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]
2023-03-30 Added uvlo circuit
    [DigitalSensor.kicad_sch, FullSchematic.kicad_pcb, FullSchematic.kicad_sch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]
2023-03-31 updated microcontroller BOM and added qr code to b.silk
    [FullSchematic.kicad_pcb, Microcontroller Schematic.kicad_sch]
2023-03-31 Confirmed part numbers and prices
    [AnalogueSensor.kicad_sch, BOM.xlsx, Charging Module.kicad_sch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]
2023-04-02 corrected connection
    [FullSchematic.kicad_pcb, Power module.kicad_sch]
2023-04-03 Checked part #s, prices, footprints
    [Charging Module.kicad_sch, FullSchematic.kicad_pcb, FullSchematic.kicad_sch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]
2023-04-03 Final Board
    [FullSchematic.kicad_pcb, Regulating Module.kicad_sch]
2023-04-04 generated files
    [AnalogueSensor.kicad_sch, Charging Module.kicad_sch, DigitalSensor.kicad_sch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]
2023-04-08 Decreased Price
    [Charging Module.kicad_sch, DigitalSensor.kicad_sch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]
2023-04-13 Uploaded final board design
    [AnalogueSensor.kicad_sch, DigitalSensor.kicad_sch, FullSchematic.kicad_pcb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]
2023-04-13 Organised repo, added instructions to ReadMe
    [AnalogueSensor.csv, AnalogueSensor.kicad_pcb, AnalogueSensor.kicad_sch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]
2023-04-24 made sure git repo is up to date
    [DigitalSensor.kicad_sch, FullSchematic.kicad_pcb]
